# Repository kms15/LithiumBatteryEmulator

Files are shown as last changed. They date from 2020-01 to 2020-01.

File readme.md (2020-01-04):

# LithiumBatteryEmulator

This is a PCB that emulates a ~4.2 volt lithium battery cell using power from
a USB connector.  It was designed to replace the battery cell in a Vocera badge
with a wall supplied power supply, but may be useful for other project too.

The board is designed to meet the Seeed studios fusion PCB assembly
requirements, including using the Seeed studio Open Part Library for
KiCad.

## License
Copyright Kendrick Shaw 2020
Licensed under the [CERN OHL v.1.2 license](http://ohwr.org/cernohl).

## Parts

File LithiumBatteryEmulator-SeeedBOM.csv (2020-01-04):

Designator | Manufacturer Part Number or Seeed SKU | Qty | Link
C10,C11,C12,C13,C14,C15,C16,C9 | TAJC107K016RNJ | 8 | https://statics3.seeedstudio.com
C2,C1,C4,C3,C7 | CC0805KKX7R8BB225 | 5 | https://statics3.seeedstudio.com
C5,C8 | CC0603KRX7R9BB104 | 2 | https://statics3.seeedstudio.com
C6 | CC0402JRNPO9BN220 | 1 | https://statics3.seeedstudio.com
J1 | ZB2001-02 | 1 | https://statics3.seeedstudio.com
L2,L3,L1,L5,L6 | BLM21PG331SN1D | 5 | https://statics3.seeedstudio.com
L4 | LQM2MPN2R2MG0 | 1 | https://statics3.seeedstudio.com
R1 | RC0603FR-071K8L | 1 | https://statics3.seeedstudio.com
R2 | RC0603FR-0724KL | 1 | https://statics3.seeedstudio.com
R4 | RC0603FR-07150KL | 1 | https://statics3.seeedstudio.com
U1 | ETA3406S2F-T | 1 | https://statics3.seeedstudio.com
USB1 | 10118193-0001LF | 1 | https://statics3.seeedstudio.com

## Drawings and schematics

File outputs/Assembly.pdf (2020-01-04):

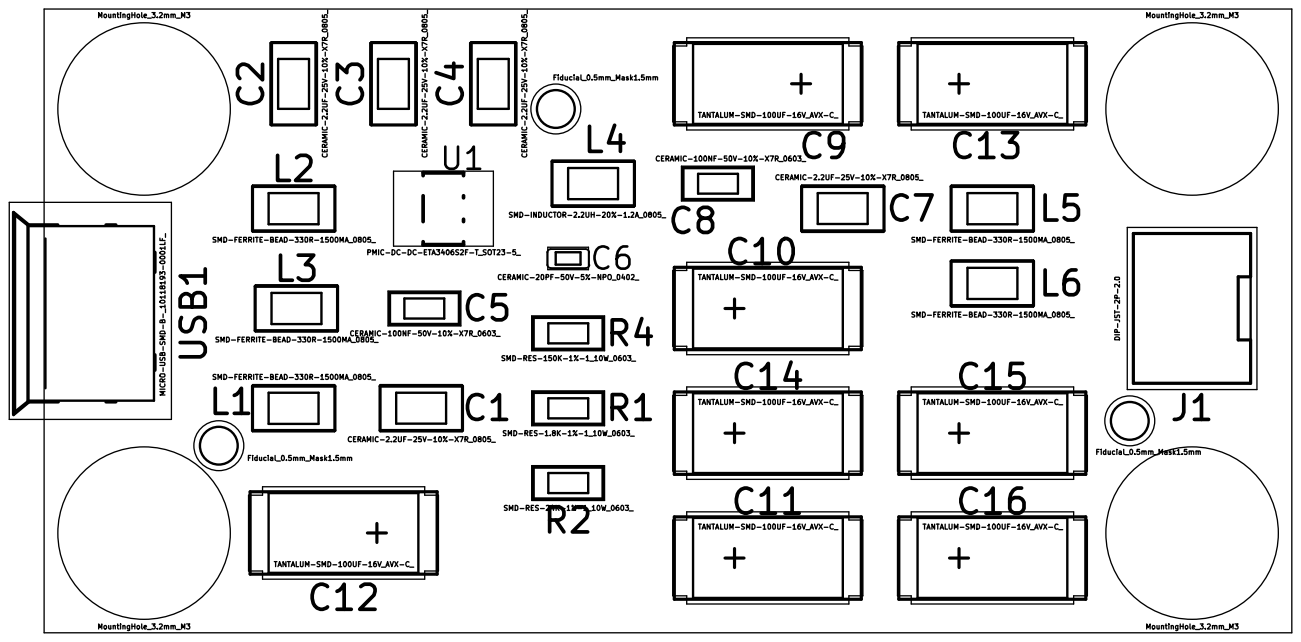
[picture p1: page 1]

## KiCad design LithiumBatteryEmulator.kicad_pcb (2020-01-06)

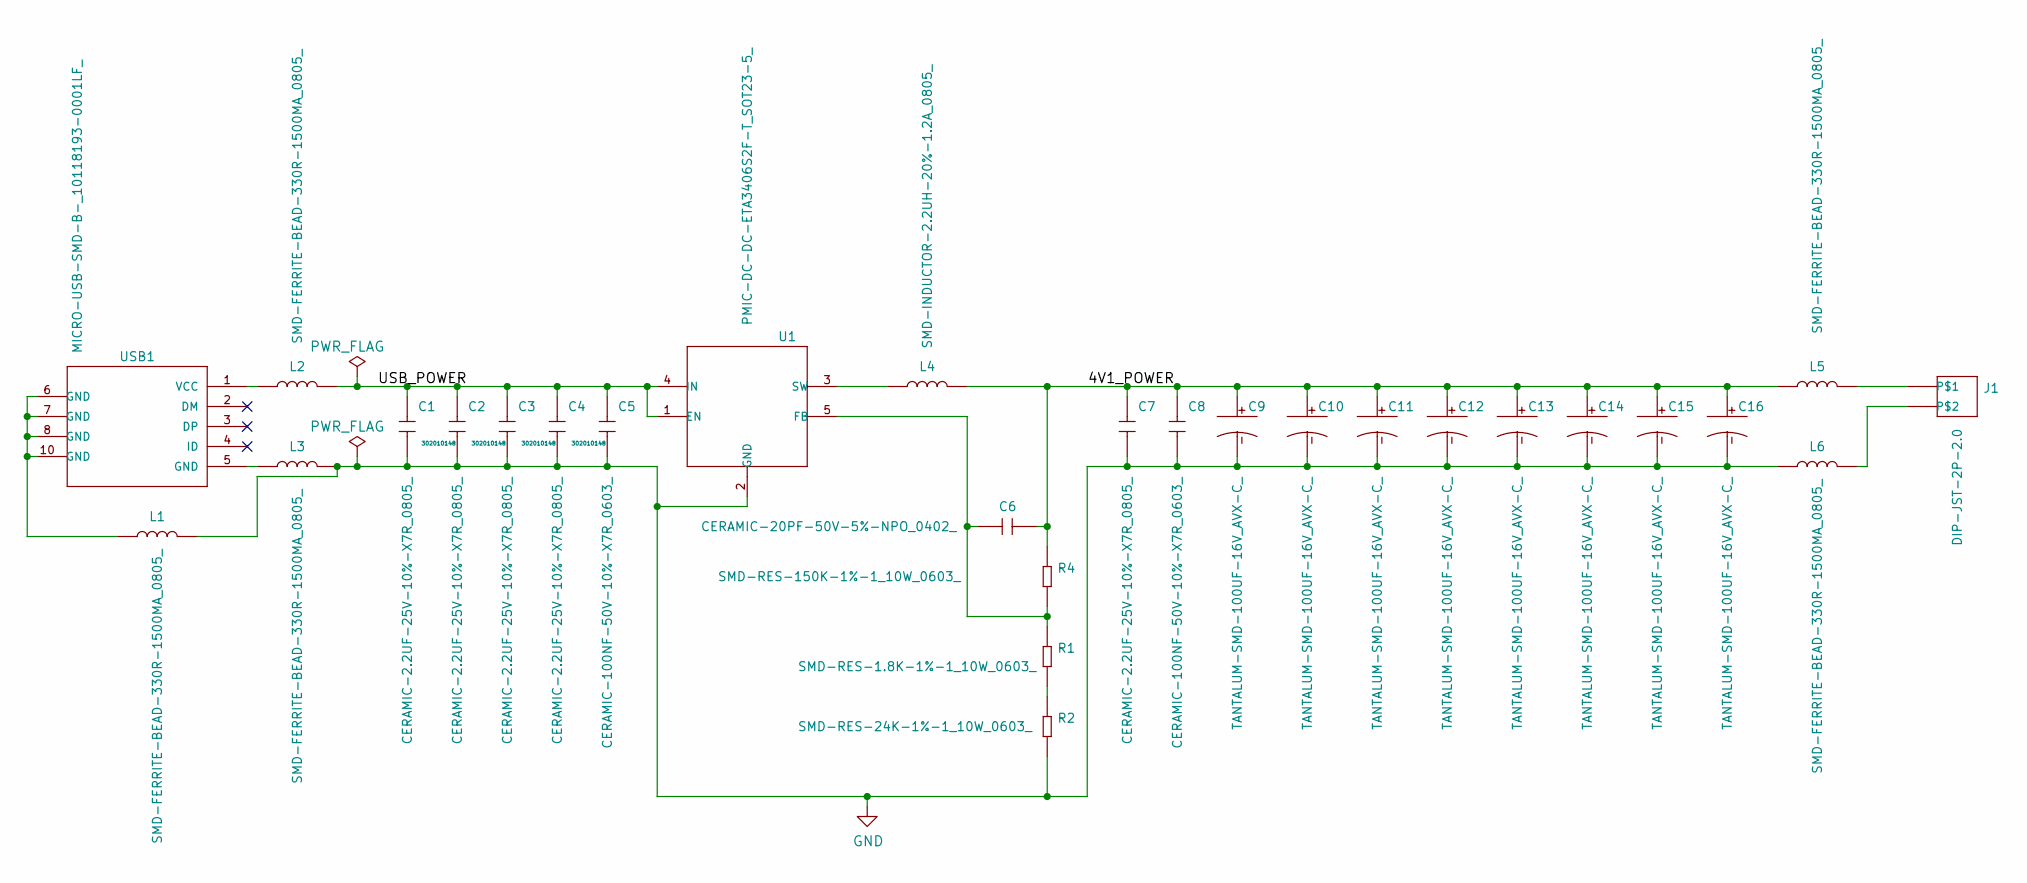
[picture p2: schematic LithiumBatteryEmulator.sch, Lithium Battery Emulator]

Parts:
C1, C2, C3, C4, C7: CERAMIC-2.2UF-25V-10%-X7R_0805_; C0805; MPN CC0805KKX7R8BB225
C5, C8: CERAMIC-100NF-50V-10%-X7R_0603_; C0603; MPN CC0603KRX7R9BB104
C6: CERAMIC-20PF-50V-5%-NPO_0402_; C0402; MPN CC0402JRNPO9BN200
C9, C10, C11, C12, C13, C14, C15, C16: TANTALUM-SMD-100UF-16V_AVX-C_; AVX-C(2312); MPN TAJC107K016RNJ
J1: DIP-JST-2P-2.0; H2-2.0-6X4.5MM
L1, L2, L3, L5, L6: SMD-FERRITE-BEAD-330R-1500MA_0805_; L0805; MPN BLM21PG331SN1D
L4: SMD-INDUCTOR-2.2UH-20%-1.2A_0805_; L0805; MPN LQM2MPN2R2MG0
R1: SMD-RES-1.8K-1%-1_10W_0603_; R0603; MPN RC0603FR-071K8L
R2: SMD-RES-24K-1%-1_10W_0603_; R0603; MPN RC0603FR-0724KL
R4: SMD-RES-150K-1%-1_10W_0603_; R0603; MPN RC0603FR-07150KL
U1: PMIC-DC-DC-ETA3406S2F-T_SOT23-5_; SOT-23-5; MPN ETA3406S2F-T
USB1: MICRO-USB-SMD-B-_10118193-0001LF_; MICRO-USB5+6P-SMD-0.65-B; MPN 10118193-0001LF

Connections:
/4V1_POWER: C6.2, C7.1, C8.1, C9.+, C10.+, C11.+, C12.+, C13.+, C14.+, C15.+, C16.+, L4.2, L5.1, R4.1
/USB_POWER: C1.1, C2.1, C3.1, C4.1, C5.1, L2.2, U1.1 (EN), U1.4 (IN)
GND: C1.2, C2.2, C3.2, C4.2, C5.2, C7.2, C8.2, C9.-, C10.-, C11.-, C12.-, C13.-, C14.-, C15.-, C16.-, L1.2, L3.2, L6.1, R2.2, U1.2 (GND)
unnamed: C6.1, R1.1, R4.2, U1.5 (FB)
unnamed: J1.1, L5.2
unnamed: J1.2, L6.2
unnamed: L1.1, USB1.6 (GND), USB1.7 (GND), USB1.8 (GND), USB1.9 (GND), USB1.10 (GND), USB1.11 (GND)
unnamed: L2.1, USB1.1 (VCC)
unnamed: L3.1, USB1.5 (GND)
unnamed: L4.1, U1.3 (SW)
unnamed: R1.2, R2.1

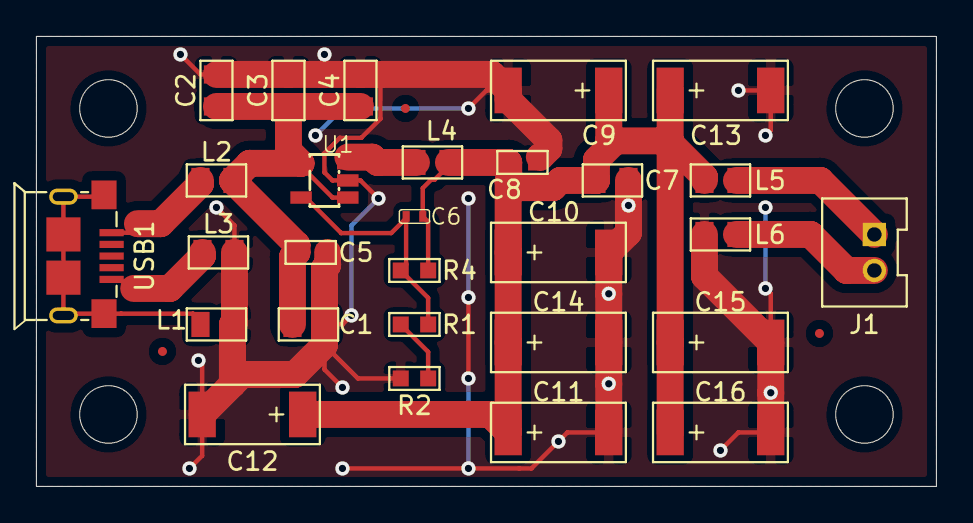
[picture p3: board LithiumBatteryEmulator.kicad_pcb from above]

Board: 2 copper layers, 50.0 x 25.0 mm, 28 parts (0 on the bottom side), 11 nets.

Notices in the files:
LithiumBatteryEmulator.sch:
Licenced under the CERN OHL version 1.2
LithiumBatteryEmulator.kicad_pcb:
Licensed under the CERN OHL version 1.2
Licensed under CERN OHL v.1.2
